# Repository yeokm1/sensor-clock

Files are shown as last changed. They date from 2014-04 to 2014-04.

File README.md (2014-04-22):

sensor-clock
============

A clock composed of an Arduino, temperature, humidity and pressure sensors.

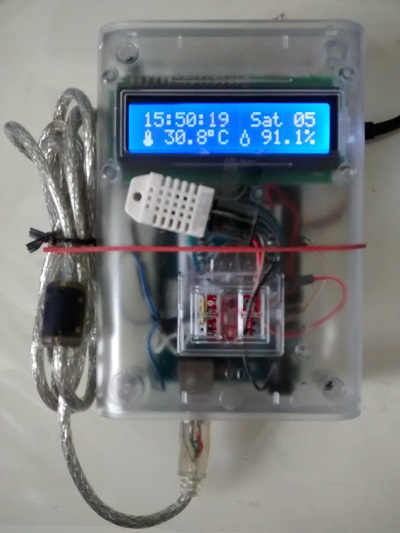
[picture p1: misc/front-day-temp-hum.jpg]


Front. The temperature and humidity reading will switch to the pressure reading and approximate altitude at regular intervals. The white DHT22 temperature/humidity sensor is placed externally to prevent heat from the Arduino from affecting the measurement.

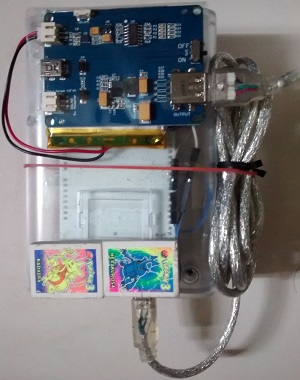
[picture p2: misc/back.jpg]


Backup Lithium battery and charger placed at the back due to space constraint. Those are erasers at the bottom to act as bumpers.

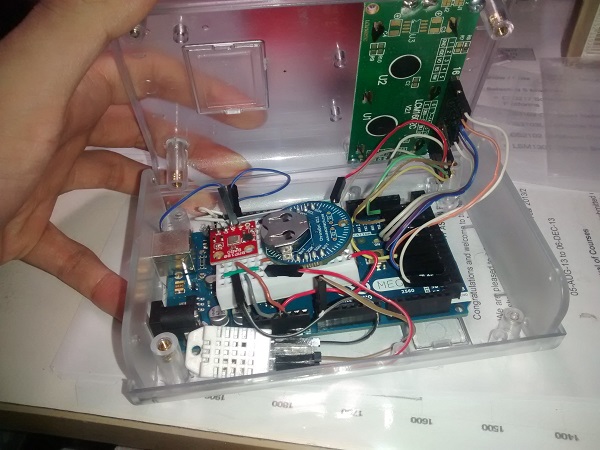
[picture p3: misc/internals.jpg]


Just for the curious.

<b>Main Parts used:</b>  

1. Arduino Mega 2560 R3  (An Uno or other boards will work too)  
2. LCD based on Hitachi HD44780  
3. DHT22 temperature and humidity sensor  
4. BMP180 Pressure and temperature sensor (Temperature sensor unused)  
5. Chronodot v2.1 Real Time Clock (Based on DS3231 temperature compensated RTC crystal. Temperature sensor unused)
6. 10k ohm resistor for DHT22 (4.7k ohm will work too)  

Optional:  

1. Half breadboard  
2. 2000 mAh Lithium battery  
3. Lipo charger  
4. Translucent case  

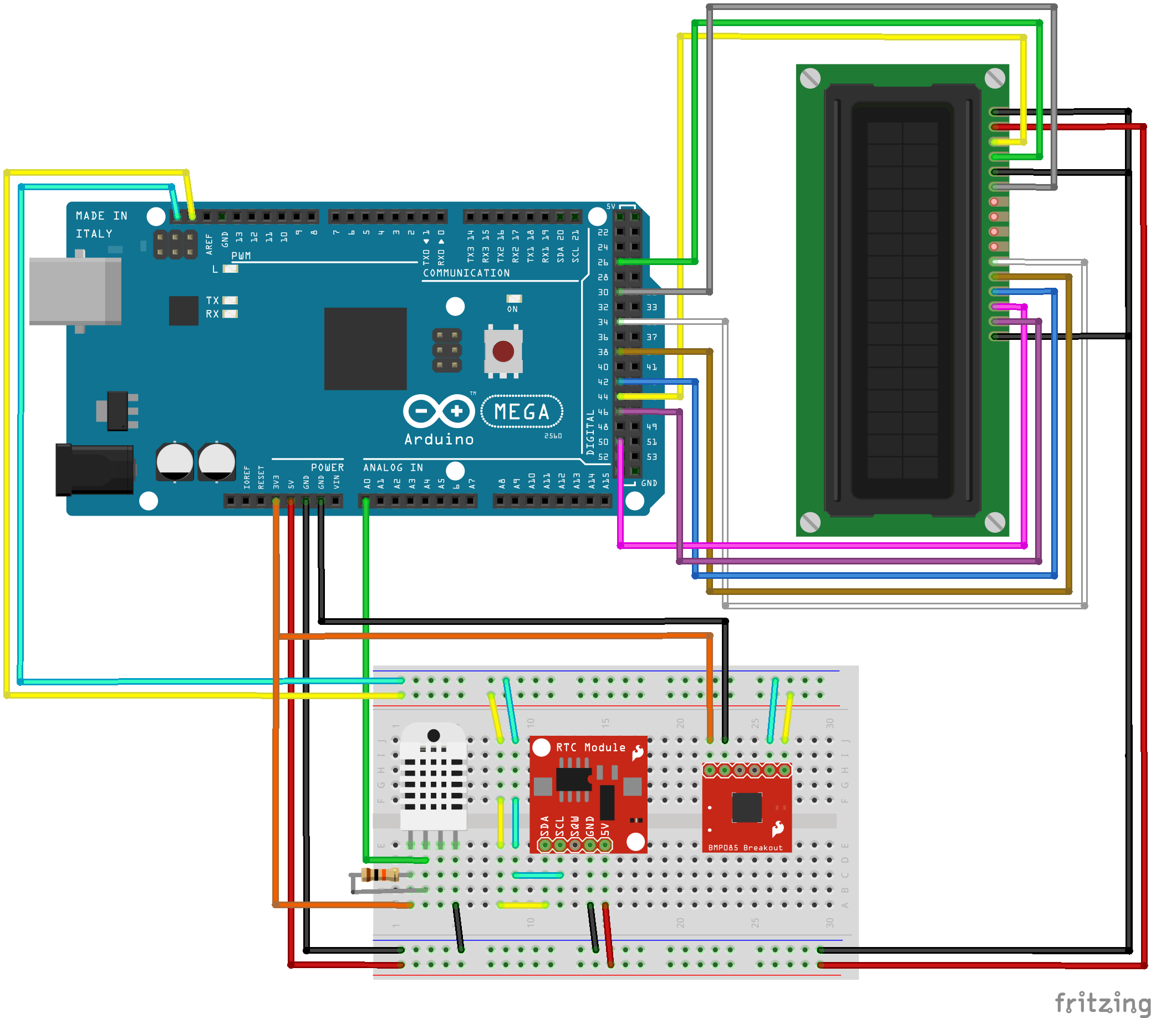
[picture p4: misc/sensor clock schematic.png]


A Fritzing schematic. This schematic only represents the logical connections I made. The physical connections differs due to space issues. As Fritzing does not have DHT22, BMP180 and DS3231 chronodot, I modified some existing and downloaded designs.

<b>Things to take note before modifying my code/design:</b>  

1. DHT22 sensor needs at least 2 seconds delay between readings.  

2. BMP180 needs to take a temperature reading (even if you do not use it) before taking a pressure reading. Both readings need a delay of 5ms each.

3. BMP180 requires a 3.3V input.

4. I set the DHT22 to use the 3.3V input although it can technically work on 5V. It seems to give more accurate readings from a 3.3V source.

5. One is supposed to add a pull-up resistor for the I2C bus lines SCL and SDA if more than one device (BMP180 and Chronodot) uses them. I tried without the resistor and it seems to work fine.

6. I used an Arduino Mega because the front digital lines are close to the LCD headers thus reducing the wire length in the cramped enclosure. An Uno will work just as well.

7. If you wish to change the LCD pins at pin 44 (Contrast) and 46 (Backlight), remember to move them to other PWM supported lines. 

8. Auto power off of lcd and sensors at set times. Can disable by setting TURN_OFF_AT_TIMES to false.

References and libraries:  

1. Using Arduino LCD without potentiometer.  
(http://engineeringlearning.blogspot.sg/2013/10/interfacing-lcd-without-potentiometer.html)

2. Get day of week from date.  
(http://stackoverflow.com/a/21235587)

2. Temperature and Humidity Icons  
(http://www.instructables.com/id/Clock-with-termometer-using-Arduino-i2c-16x2-lcd-D/)  

3. Adafruit DHT sensor library  
(https://github.com/adafruit/DHT-sensor-library)

4. Adafruit DS1307 RTC library (Works for DS3231 too. I used this because of a neat feature of setting the clock to compilation time after every upload)  
(https://github.com/adafruit/RTClib)

5. Sparkfun BMP180 library  
(https://github.com/sparkfun/BMP180_Breakout)

7. New Liquid Crystal library (for supposedly better LCD performance)  
(https://bitbucket.org/fmalpartida/new-liquidcrystal/wiki/Home)

8. Ports library from jeelibs to save power during delay  
(https://github.com/jcw/jeelib)

The MIT License (MIT)<br>
Copyright (c) 2014-2014 Yeo Kheng Meng<br>

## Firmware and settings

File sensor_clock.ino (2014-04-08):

#include <RF12.h> 
#include <JeeLib.h>
#include <PortsLCD.h> //Replaces the LiquidCrystal.h

#include <Wire.h>
#include <DHT.h>
#include <SFE_BMP180.h>
#include <RTClib.h>


#define LED_13_PIN 13

#define DHTPIN A0 
#define DHTTYPE DHT22 
#define BASE_PRESSURE 1012.0 //Sea level pressure in millibars. Calibrate if you must

#define CONTRAST_PIN 44  //Make sure this is on a PWM pin. I'm using the Arduino Mega 2560 R3 so pin number will differ for others.
#define BACKLIGHT_PIN 46   //Make sure this is on a PWM pin
#define BACKLIGHT_BRIGHTNESS 0   //PWM value  I don't need the backlight so set to 0
#define CONTRAST 0             //PWM value  You may need to change this value

#define LCD_CHAR_LENGTH 16

#define LCD_DEGREES_SYMBOL (char) 223

#define REFRESH_INTERVAL 5 //Minimum 5 seconds for DHT22 to refresh. Do not exceed 59
#define SWAP_LINE2_Interval 15 //Must be multiple of refresh interval. Do not exceed 59

#define SLEEP_INTERVAL 250 //0.25s
#define SLEEP_LONG_INTERVAL 45000 //45s

#define OFF_HOUR 01
#define OFF_MIN 00

#define ON_HOUR 06
#define ON_MIN 30

#define TURN_OFF_AT_TIMES true  //Set to false if you don't want the screen and readings to stop at certain times.

#define THERM_ICON_REP 1
#define HUM_ICON_REP 2

//Icons from http://www.instructables.com/id/Clock-with-termometer-using-Arduino-i2c-16x2-lcd-D/
byte thermIcon[8] = //icon for thermometer
{
  B00100,
  B01010,
  B01010,
  B01110,
  B01110,
  B11111,
  B11111,
  B01110
};

byte humIcon[8] = //icon for humidity
{
  B00100,
  B00100,
  B01010,
  B01010,
  B10001,
  B10001,
  B10001,
  B01110,
};


//LCD wiring without POT from http://engineeringlearning.blogspot.sg/2013/10/interfacing-lcd-without-potentiometer.html
LiquidCrystal lcd(26, 30, 34, 38, 42, 50);
DHT dht(DHTPIN, DHTTYPE);
SFE_BMP180 pressure;
RTC_DS1307 RTC;  //Code for this works although I use DS3231. For the initial time setting convenience.
ISR(WDT_vect) { Sleepy::watchdogEvent(); } // Setup for low power waiting


int prevIntervalReadingSecond = 0;
int prevUpdateTimeSecond = 0;
int prevUpdateTurnOnAndOffMinute = 0;

bool showLine1OrLine2 = false;  //True for Line 1: Temperature, Humidity. False for Line 2: Pressure

bool currentlyOn = true;

void setup(){
  Serial.begin(9600);
  
  //Disable LED Pin 13 (Optional). I just hate the constant LED light.
  pinMode(LED_13_PIN, OUTPUT);
  digitalWrite(LED_13_PIN, LOW);
  
  //Start RTC
  Wire.begin();
  RTC.begin();
  
  if (!RTC.isrunning()) {
    Serial.println("RTC is NOT running");
  }

  // This section grabs the current datetime and compares it to
  // the compilation time.  If necessary, the RTC is updated.
  DateTime now = RTC.now();
  DateTime compiled = DateTime(__DATE__, __TIME__);
  
  if (now.unixtime() < compiled.unixtime()) {
    Serial.println("RTC is older than compile time! Updating");
    RTC.adjust(DateTime(__DATE__, __TIME__));
  }
  
  //Start LCD
  pinMode(CONTRAST_PIN, OUTPUT);
  pinMode(BACKLIGHT_PIN, OUTPUT);
  analogWrite(CONTRAST_PIN,CONTRAST);
  analogWrite(BACKLIGHT_PIN,BACKLIGHT_BRIGHTNESS);
  lcd.begin(LCD_CHAR_LENGTH, 2);


  lcd.createChar(THERM_ICON_REP,thermIcon);
  lcd.createChar(HUM_ICON_REP,humIcon);
  
  printThisOnLCDLine("By:", 1);
  printThisOnLCDLine("Yeo Kheng Meng", 2);


  //Start DTT
  dht.begin();
  

  //Start BMP180
  if (pressure.begin()){
    Serial.println("BMP180 init success");
  } else{
    Serial.println("BMP180 init fail\n\n");
  }
}

void loop(){
  DateTime now = RTC.now(); 


  int second = now.second();  
  int minute = now.minute();
  int hour = now.hour();

  if(currentlyOn){

  //Update time only if second changes. Prevent needless requests to LCD
    if(second != prevUpdateTimeSecond){
      prevUpdateTimeSecond = second;
      String dateString = generateDateTimeString(now.year(), now.month(), now.day(), now.hour(), now.minute(), now.second());
      printThisOnLCDLine(dateString, 0);
    }



  //Every refresh interval
    if((second % REFRESH_INTERVAL) == 0 && second != prevIntervalReadingSecond){
      //Prevent multiple readings every interval
      prevIntervalReadingSecond = second;
      Serial.println();
      Serial.print("Take DHT22 Readings: ");
      
      
      float DHTTemp = dht.readTemperature();
      float DHTHum = dht.readHumidity();
      

      Serial.print(DHTHum);
      Serial.print("\t");
      Serial.println(DHTTemp);
      
      int measureDelay;

      // You must first get a temperature measurement to perform a pressure reading.

      measureDelay = pressure.startTemperature();

      delay(measureDelay);

      double BMPTemp;
      int status = pressure.getTemperature(BMPTemp);

     // Print out the measurement:
      
      Serial.print("BMP180 readings: ");
      Serial.print(BMPTemp,2);
      Serial.print(" deg C, ");
      
     // Start a pressure measurement:
     // The parameter is the oversampling setting, from 0 to 3 (highest res, longest wait).
     // If request is successful, the number of ms to wait is returned.
     // If request is unsuccessful, 0 is returned.
      measureDelay = pressure.startPressure(0);

      delay(measureDelay);

      double BMPPress;
      status = pressure.getPressure(BMPPress,BMPTemp);
      Serial.print("abs pressure: ");
      Serial.print(BMPPress,2);
      Serial.print(" mb, ");

      float BMPAlt = pressure.altitude(BMPPress,BASE_PRESSURE);
      Serial.print("computed altitude: ");
      Serial.print(BMPAlt,0);
      Serial.println(" meters");


      if((second % SWAP_LINE2_Interval) == 0){
        showLine1OrLine2 = !showLine1OrLine2;
      }


      String lcdLine2;

      if(showLine1OrLine2){
       generateAndPrintTempHumString(DHTTemp, DHTHum); 
      } else {
       lcdLine2 = generatePressureString(BMPPress, BMPAlt);
       printThisOnLCDLine(lcdLine2, 1);
      }
    


  }
}




  //Prevent too many execution since only need to check once a minute
  if(TURN_OFF_AT_TIMES && prevUpdateTurnOnAndOffMinute != minute){
    prevUpdateTurnOnAndOffMinute= minute;
  
    Serial.println("Checking time");
    if(currentlyOn){
    
      if(hour == OFF_HOUR && minute == OFF_MIN){
        currentlyOn = false;
        lcd.noDisplay();
        longSleep();
      }
    
   } else {

    if(hour == ON_HOUR && minute == ON_MIN){
      currentlyOn = true;
      lcd.display();

    } else {
      longSleep();
    }

   }
  } 
  

 shortSleep();


}

void shortSleep(){
   Sleepy::loseSomeTime(SLEEP_INTERVAL);    
        
}


void longSleep(){
  Sleepy::loseSomeTime(SLEEP_LONG_INTERVAL);
}


void generateAndPrintTempHumString(float temp, float hum){

  String tempString = ftoa(temp, 1);
  String humString = ftoa(hum, 1);
  
  String intermediate1 = " " + tempString + LCD_DEGREES_SYMBOL + "C ";
  String intermediate2 = " " + humString + "%";
  
  lcd.setCursor (0, 1);
  lcd.write((byte) THERM_ICON_REP);
  lcd.print(intermediate1);
  lcd.write((byte) HUM_ICON_REP);
  lcd.print(intermediate2);
  
}


String generateTempHumString(float temp, float hum){
  String tempString = ftoa(temp, 1);
  String humString = ftoa(hum, 1);
  String result = "P:" + tempString + LCD_DEGREES_SYMBOL + "C H:" + humString + "%";
  return result;
  
}

String generatePressureString(double pressure, double altitude){
  String pressString = ftoa(pressure, 1);
  int alt = altitude + 0.5;  //Round to nearest integer
  
  String result = "P:" + pressString + "mb " + alt + "m";
  return result;

}



//Convert float/double to String as ardiuno sprintf does not support float/double
String ftoa(double f, int precision)
{
  long p[] = {0,10,100,1000,10000,100000,1000000,10000000,100000000};
  
  char temp[5];
  char * a = temp;
  long heiltal = (long)f;
  itoa(heiltal, a, 10);
  while (*a != '\0') a++;
  *a++ = '.';
  long desimal = abs((long)((f - heiltal) * p[precision]));
  itoa(desimal, a, 10);
  String result = temp;
  return result;
}

void printThisOnLCDLine(String text, int line){

  //Clear current line only if the new line cannot occupy the old line
  if(text.length() < LCD_CHAR_LENGTH){
    lcd.setCursor (0, line);  
    lcd.print("                "); 
  }

  lcd.setCursor (0, line);  
  lcd.print(text);
}

String generateDateTimeString(int year, int month, int day, int hour, int minute, int second){
  char buff[3];

  sprintf(buff, "%02d", hour);
  String hourString = buff;

  sprintf(buff, "%02d", minute);
  String minuteString = buff;
  
  sprintf(buff, "%02d", second);
  String secondString = buff;
  
  String result = hourString + ":" + minuteString + ":" + secondString + " ";
  
  String dayOfWeek = getDayOfTheWeek(year, month, day);
  
  sprintf(buff, "%02d", day);
  String dayString = buff;

  String monthString = getMonth(month);
  
  if(0 <= second && second <= 40){
    result += " " + dayOfWeek + " " + dayString;
  } else {
    result += monthString + year;
  }
  return result;
}



// From http://stackoverflow.com/a/21235587
String getDayOfTheWeek(int y, int m, int d) {
  String weekdayname[] = {"Sun", "Mon", "Tue",
  "Wed", "Thu", "Fri", "Sat"};

  int weekday = (d+=m<3?y--:y-2,23*m/9+d+4+y/4-y/100+y/400)%7;
  
  
  return weekdayname[weekday];
}

String getMonth(int month){
  switch(month){
    case 1: return "Jan";
    case 2: return "Feb";
    case 3: return "Mar";
    
    case 4: return "Apr";
    case 5: return "May";
    case 6: return "Jun";
    
    case 7: return "Jul";
    case 8: return "Aug";
    case 9: return "Sep";
    
    case 10: return "Oct";
    case 11: return "Nov";
    case 12: return "Dec";
    default : return "Nil";
  }

}

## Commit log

2014-04-04 Disable LED pin 13
2014-04-05 fitzing schematic
    [sensor clock.fzz]
2014-04-05 picture schematic
2014-04-05 cut resolution
2014-04-06 add 10kohm resistor
    [sensor clock.fzz]
2014-04-06 Update README.md
    Removed DHT22 resistor comment now that I added the resistor back.
2014-04-08 new schematic to reflect changes in DHT22 to 3.3V
    [sensor clock.fzz]
2014-04-08 Use jeelibs low power library
